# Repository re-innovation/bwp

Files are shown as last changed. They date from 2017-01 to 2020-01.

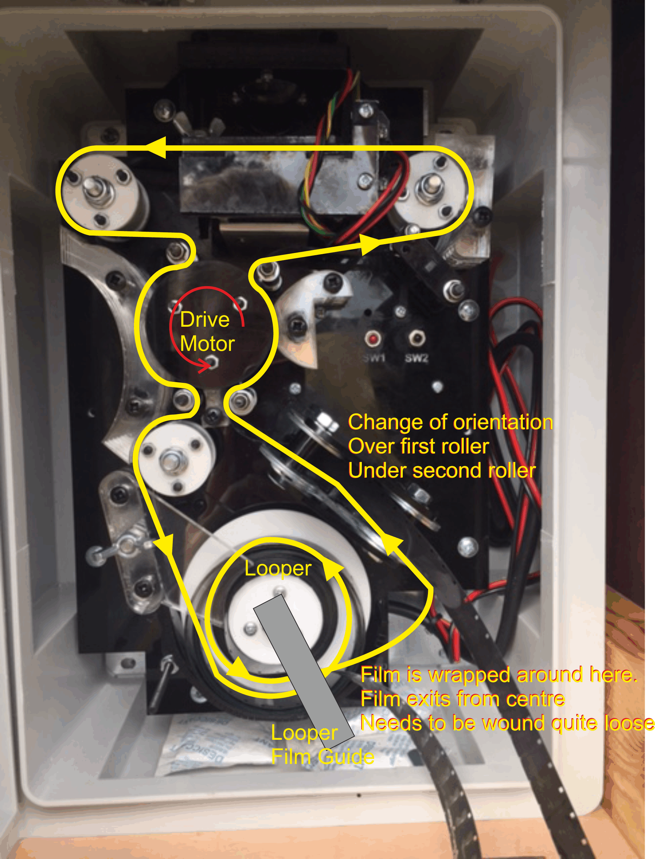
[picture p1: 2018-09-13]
Projection_Unit_Documentation/Kinetiscope Film Document.png

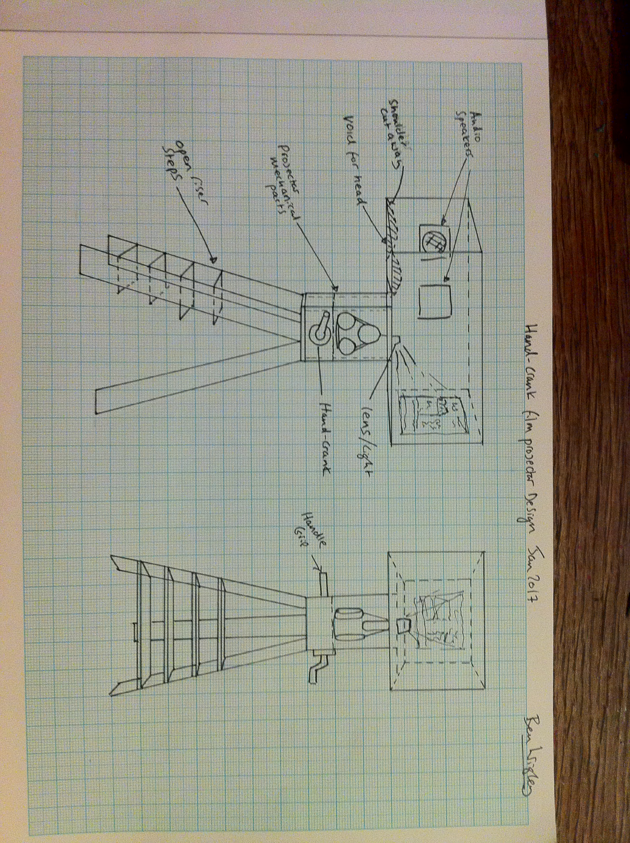
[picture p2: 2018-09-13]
Projection_Unit_Documentation/photo.JPG

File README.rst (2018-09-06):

===
BWP
===

This is the code and the design files for a low power LED projector unit which utilises real film.
It is quite complex and probably best explained via this link and video:

https://www.re-innovation.co.uk/portfolio/kinetiscopes-a-lost-paradise/

This repository has the full code (done by Matthew Mouse Gates) and the full design files (done by Matthew Little).

The desgin files have been produced using Corel Draw, but have been also saved as .dxf and .svg files. 

********
Controls
********

SW1 cycles through modes as follows:

- Setup: manual feed (SW2 feeds film)
- Setup: frame offset adjustment (SW2 adjusts the frame offset)
- Setup: volume adjustment (SW2 adjusts the volume)
- Setup: number of uses (readout)
- Setup: total runtime (readout)
- Setup: average runtime (readout)
- Normal Mode

****************
Heartbeat States
****************

The indicator LED is used to convey the state of the system by flashing one of the following sequences:

- Normal (50ms on, 500ms off) - the projector is running
- Slow (1000ms on, 150ms off) - the system has browned out, but still running
- Quick (25ms on, 25ms off) - the system is in configuration mode
- Slowest (1000ms on, 1000ms off) - the system has just powered up, but not exited brownout mode yet

**************
Pre-requisites
**************

* Install the Arduino IDE 1.6.6 or later:
    * Windows & Mac users may find a download link here: https://www.arduino.cc/en/Main/Software
    * Major Linux distros carry it in their software repositories, or the link above may be used
* Install *AccelStepper* library.
* Install *Mutila* library, link: https://github.com/matthewg42/Mutila 

******************************
Building Using the Arduino IDE
******************************

This method is preferred on Windows and for casual users who just want to build and use the project.

* Open Arduino IDE 
* Open firmware/firmware.ino
* Set the board to "Arduino Nano" (under the Tools -> Board menu)
* Connect Nano 
* Click the Upload button on the tool bar

*******************
Using make on Linux
*******************

This alternative build system may also be used. It is an alternative to using the Arduino IDE and may be preferred by some users. 

* Install the Arduino-Makefile system: https://github.com/sudar/Arduino-Makefile
* Edit the arduino.mk file and set the include line to point at where you installed Arduino-Makefile (or set the ARDUINO_MAKEFILE environment variable)
* In a shell, from the *firmware* directory, use the command "make upload" to build and install the code

****************
Uploading Sounds
****************

Sounds must be within a folder called "mp3" on the SD card.
Sounds are numbers 0001 to 9999.

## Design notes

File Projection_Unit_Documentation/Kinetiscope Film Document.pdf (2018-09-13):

To remove film - cut at break in film and re-fix.
This needs the film editing cutter.

To get film tension correct:
Ensure the film is wrapped around the looper and that the tension is OK (there needs to be enough space in the film to allow the centre film to exit the looper from the middle).
Use the drive motor to pull the film around. This can be rotated by hand when the unit is not powered.
The drive motor teeth must engage in the film holes.
Sometimes this slips, but should restore itself.

With lots of film then the film around the looper might pull tight and stick.
The film needs to be loosened by careful pulling and ‘shuffling’ of the film. Use the drive motor to pull the film around a few times. This will help loosen the film around the looper. This can be done by carefully turning the drive motor by hand (do not do this with power applied or crank turned).

The looper film guide stops all the film from springing off the looper.
The angle of the looper film guide can be altered to ensure the film is kept in place.
For the arch unit it was found to be best positioned at an angle of 5 c’clock. Ensure the film can feed through easily when the drive motor is turned.

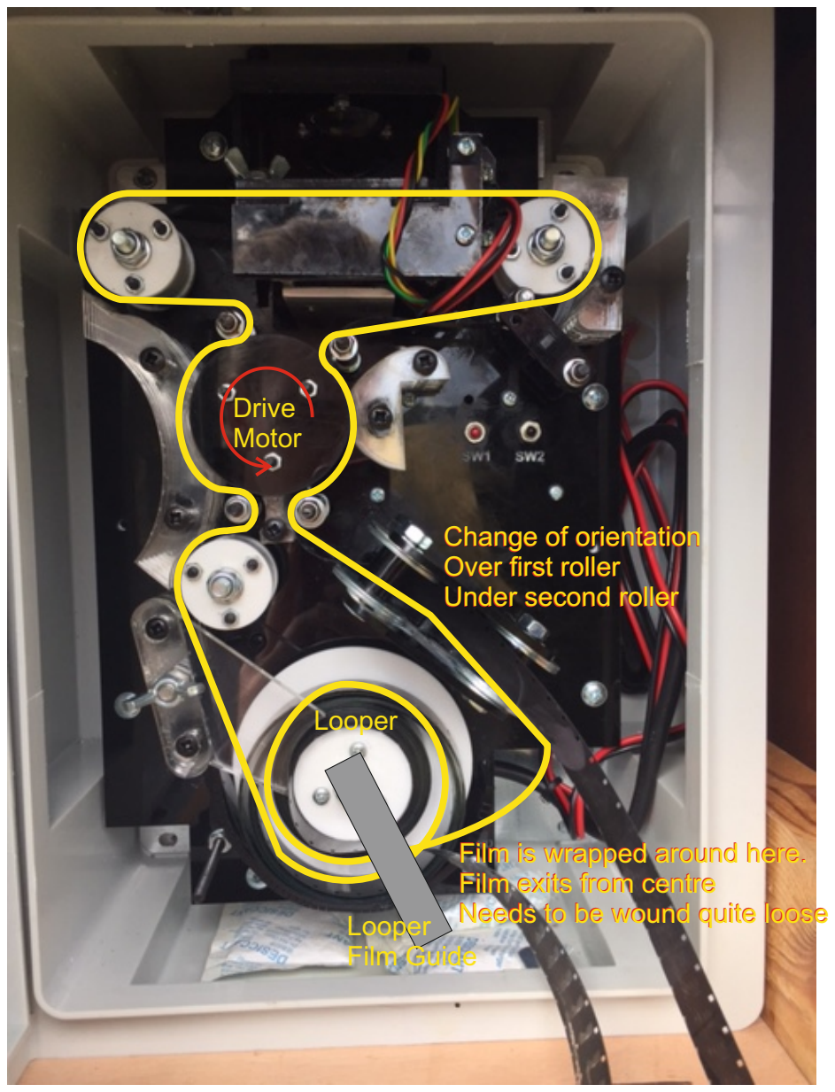
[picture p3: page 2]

Change of orientation
Over first roller
Under second roller

Film is wrapped around here. Film exits from centre
Needs to be wound quite loose

Change of orientation
Over first roller
Under second roller

Looper

Drive
Motor

Looper
Film Guide

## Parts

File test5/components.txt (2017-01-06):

Shutter
	open()
	close()

Mp3Player
	play(n)

Stepper
	advance()
	
FrameSync
	frameDetect
		Stepper.advance()
		Shutter.open()
		Shutter.close()

Mp3PlayerSyncSensor
	codeDetect
		Mp3Player.play(n)

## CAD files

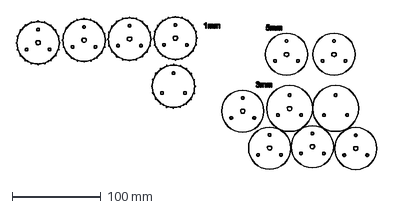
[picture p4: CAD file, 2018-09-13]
Projection_Unit_Hardware/Projection_Unit_Build/16mm_Film_Reel_Holder_7.dxf
407.2 x 173.0 mm

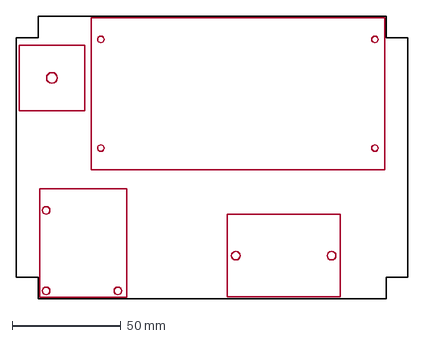
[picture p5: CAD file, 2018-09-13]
Solar Power Supply/Solar_Power_Supply_baseplate.dxf
180.0 x 130.0 mm

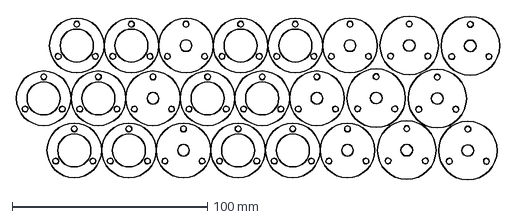
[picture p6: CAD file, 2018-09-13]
Projection_Unit_Hardware/Projection_Unit_Build/16mm_Film_Tension_roller_and_Feed_Rollers.dxf
247.6 x 83.9 mm

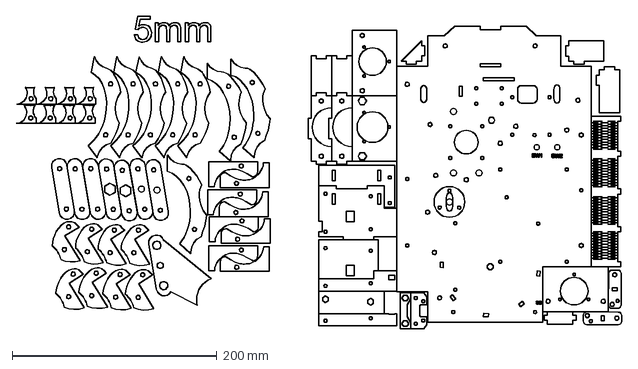
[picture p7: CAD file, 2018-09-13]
Projection_Unit_Hardware/Projection_Unit_Build/2017_5_3_Layout of components_v2_no_outline.dxf
591.4 x 305.5 mm

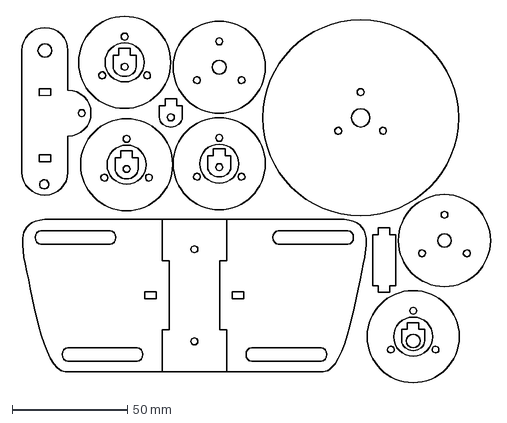
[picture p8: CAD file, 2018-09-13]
Projection_Unit_Hardware/Projection_Unit_Build/2017_4_6_Looper Design.dxf
205.8 x 159.1 mm

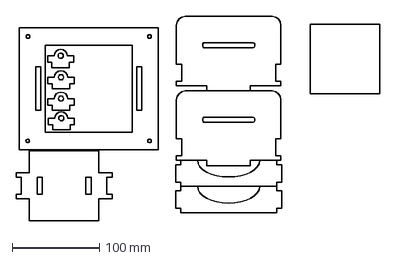
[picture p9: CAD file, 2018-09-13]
Projection_Unit_Hardware/Projection_Unit_Build/Mirror Holder.dxf
417.6 x 234.6 mm

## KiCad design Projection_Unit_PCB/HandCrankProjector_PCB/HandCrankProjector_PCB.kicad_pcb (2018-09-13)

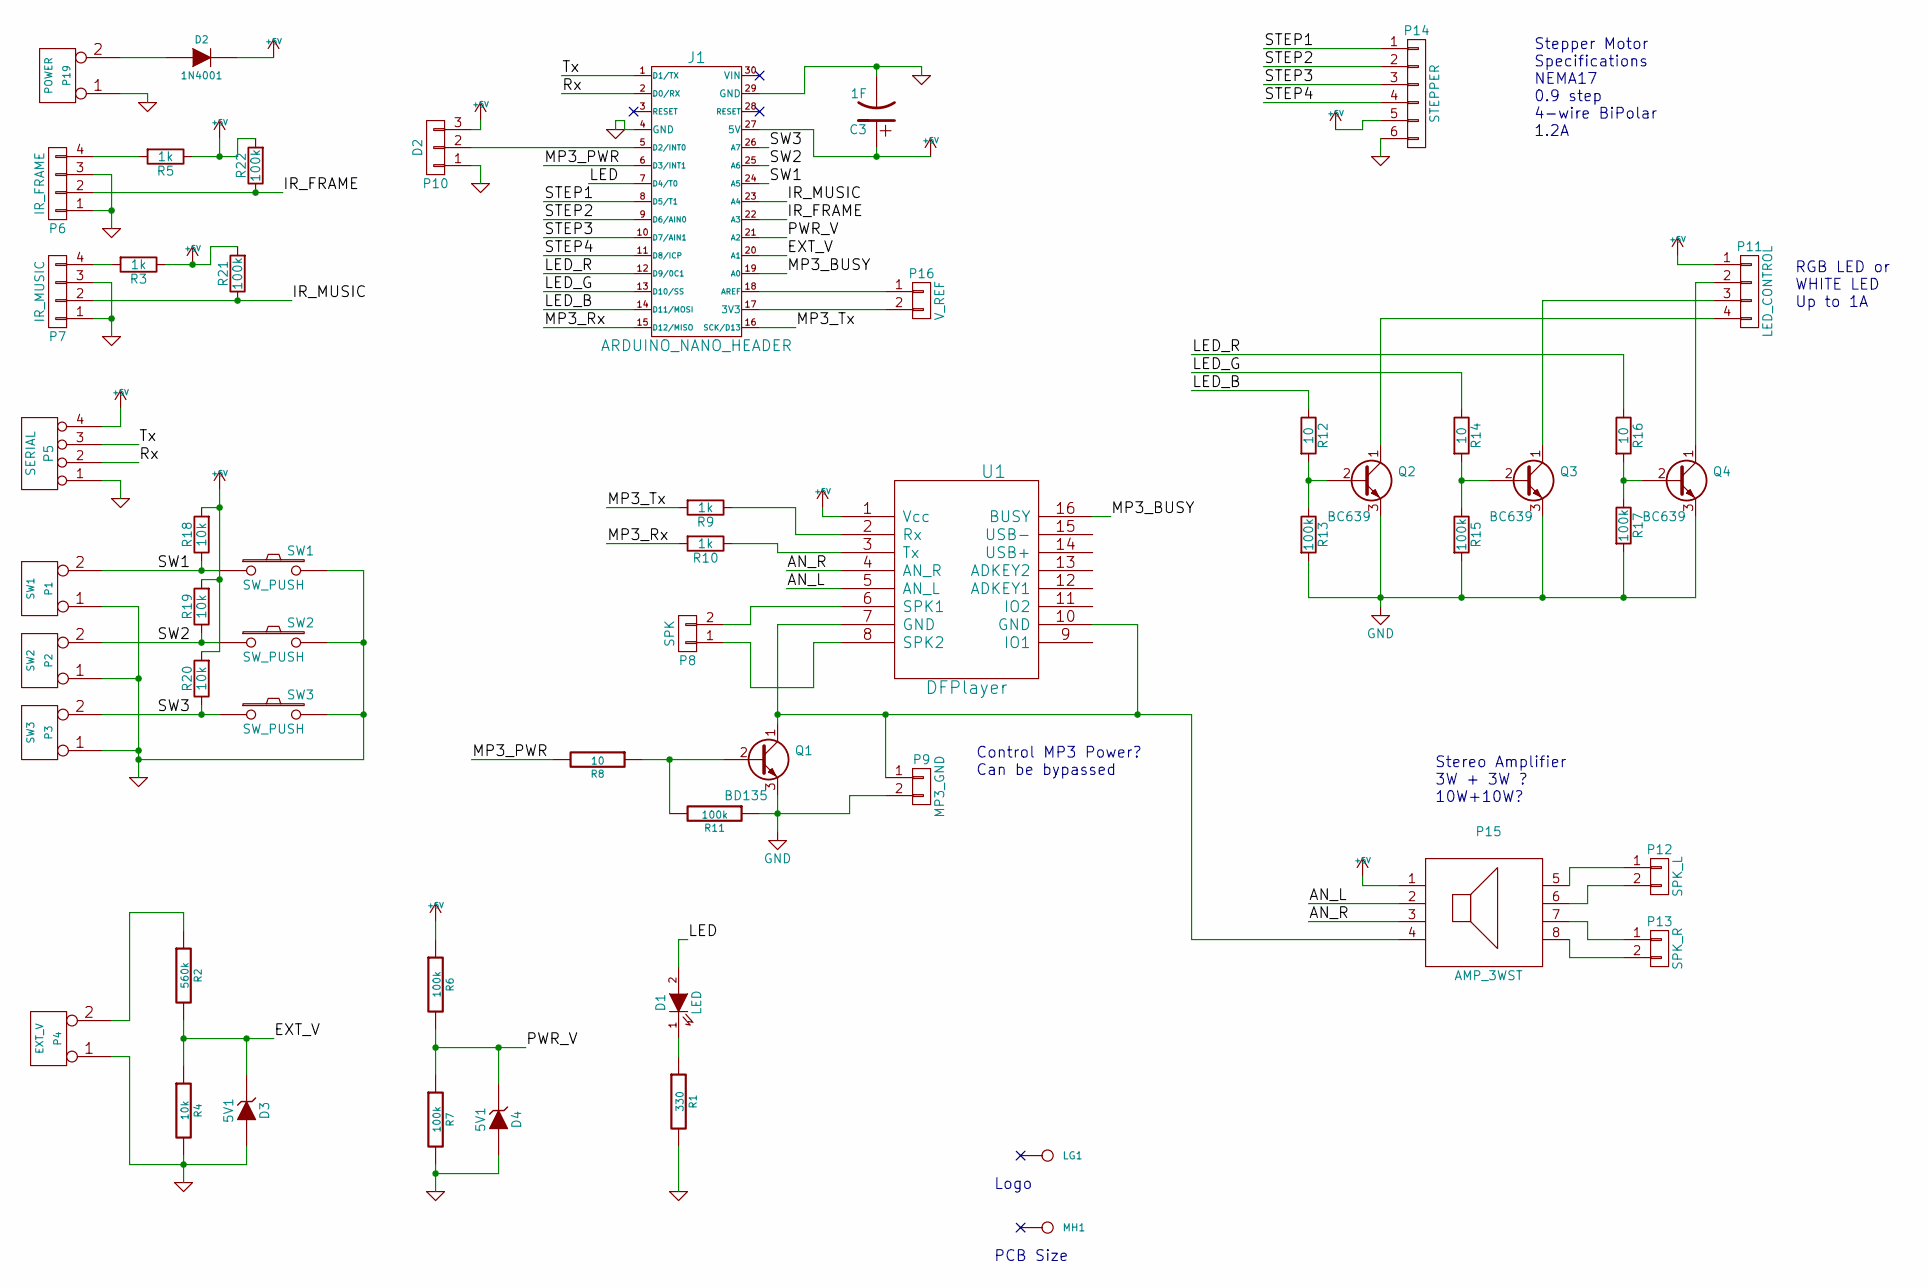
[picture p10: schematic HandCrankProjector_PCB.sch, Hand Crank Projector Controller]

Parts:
C3: 1F; C_1F_SuperCap; Manufacturer Part No Value
D1: LED; TH_LED-5MM_larg_pad
D2: 1N4001; TH_Diode_1
D3, D4: 5V1; TH_Diode_1
J1: ARDUINO_NANO_HEADER; NANO_DIP_30_600
LG1: CONN_1; reinnovation_logo_15mm
MH1: CONN_1; PCB_75x100mm
P1: SW1; SIL-2_large_hole
P2: SW2; SIL-2_large_hole
P3: SW3; SIL-2_large_hole
P4: EXT_V; SIL-2_screw_terminal
P5: SERIAL; SIL-4_Grove_SIL
P6: IR_FRAME; SIL-4_Grove_SIL
P7: IR_MUSIC; SIL-4_Grove_SIL
P8: SPK; SIL-2_screw_terminal
P9: MP3_GND; SM_2_SLDR_JMP
P10: D2; Pin_Header_Straight_1x03
P11: LED_CONTROL; SIL-4_Grove_SCREW
P12: SPK_L; SIL-2_screw_terminal
P13: SPK_R; SIL-2_screw_terminal
P14: STEPPER; TH_6W_SCREW_TERM
P15: AMP_3WST; TH_PAM8403_Amp
P16: V_REF; SM_2_SLDR_JMP
P19: POWER; SIL-2_screw_terminal; Manufacturer Part No Value
Q1: BD135; TO92-ECB_large_pad_BC639
Q2, Q3, Q4: BC639; TO92-ECB_large_pad_BC639
R1: 330; TH_Resistor_1; Manufacturer Part No Value
R2: 560k; TH_Resistor_1; Manufacturer Part No Value
R3, R5, R9, R10: 1k; TH_Resistor_1
R4: 10k; TH_Resistor_1; Manufacturer Part No Value
R6, R7, R11: 100k; TH_Resistor_1; Manufacturer Part No Value
R8: 10; TH_Resistor_1; Manufacturer Part No Value
R12, R14, R16: 10; TH_Resistor_1
R13, R15, R17, R21, R22: 100k; TH_Resistor_1
R18, R19, R20: 10k; TH_Resistor_1
SW1, SW2, SW3: SW_PUSH; SW_PUSH_single_pins
U1: DFPlayer; TH_DFPlayer_Mini

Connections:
+5V: C3.1, D2.2 (K), J1.27 (5V), P5.4, P10.3, P11.1, P14.5, P15.1, R3.1, R5.1, R6.1, R18.2, R19.2, R20.2, R21.2, R22.2, U1.1 (Vcc)
/AN_L: P15.2, U1.5 (AN_L)
/AN_R: P15.3, U1.4 (AN_R)
/EXT_V: D3.2 (K), J1.20 (A1), R2.2, R4.1
/IR_FRAME: J1.22 (A3), P6.2, R22.1
/IR_MUSIC: J1.23 (A4), P7.2, R21.1
/LED: D1.2 (A), J1.7 (D4/T0)
/LED_B: J1.14 (D11/MOSI), R12.1
/LED_G: J1.13 (D10/SS), R14.1
/LED_R: J1.12 (D9/0C1), R16.1
/MP3_BUSY: J1.19 (A0), U1.16 (BUSY)
/MP3_PWR: J1.6 (D3/INT1), R8.2
/MP3_Rx: J1.15 (D12/MISO), R10.2
/MP3_Tx: J1.16 (SCK/D13), R9.2
/PWR_V: D4.2 (K), J1.21 (A2), R6.2, R7.1
/Rx: J1.2 (D0/RX), P5.2
/STEP1: J1.8 (D5/T1), P14.1
/STEP2: J1.9 (D6/AIN0), P14.2
/STEP3: J1.10 (D7/AIN1), P14.3
/STEP4: J1.11 (D8/ICP), P14.4
/SW1: J1.24 (A5), P1.2 (PM), R18.1, SW1.1
/SW2: J1.25 (A6), P2.2 (PM), R19.1, SW2.1
/SW3: J1.26 (A7), P3.2 (PM), R20.1, SW3.1
/Tx: J1.1 (D1/TX), P5.3
GND: C3.2, D3.1 (A), D4.1 (A), J1.4 (GND), J1.29 (GND), P1.1, P2.1, P3.1, P4.1, P5.1, P6.1, P6.3, P7.1, P7.3, P9.2, P10.1, P14.6, P19.1, Q1.3 (E), Q2.3 (E), Q3.3 (E), Q4.3 (E), R1.2, R4.2, R7.2, R11.1, R13.2, R15.2, R17.2, SW1.2, SW2.2, SW3.2
unnamed: D1.1 (K), R1.1
unnamed: D2.1 (A), P19.2 (PM)
unnamed: J1.5 (D2/INT0), P10.2
unnamed: J1.17 (3V3), P16.2
unnamed: J1.18 (AREF), P16.1
unnamed: P4.2 (PM), R2.1
unnamed: P6.4, R5.2
unnamed: P7.4, R3.2
unnamed: P8.1, U1.8 (SPK2)
unnamed: P8.2, U1.6 (SPK1)
unnamed: P11.2, Q4.1 (C)
unnamed: P11.3, Q3.1 (C)
unnamed: P11.4, Q2.1 (C)
unnamed: P12.1, P15.5
unnamed: P12.2, P15.6
unnamed: P13.1, P15.7
unnamed: P13.2, P15.8
unnamed: P9.1, P15.4, Q1.1 (C), U1.7 (GND), U1.10 (GND)
unnamed: Q1.2 (B), R8.1, R11.2
unnamed: Q2.2 (B), R12.2, R13.1
unnamed: Q3.2 (B), R14.2, R15.1
unnamed: Q4.2 (B), R16.2, R17.1
unnamed: R9.1, U1.2 (Rx)
unnamed: R10.1, U1.3 (Tx)

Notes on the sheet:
PCB Size
Stepper Motor Specifications NEMA17 0.9 step 4-wire BiPolar 1.2A
Stereo Amplifier 3W + 3W ? 10W+10W?
Control MP3 Power? Can be bypassed
RGB LED or WHITE LED Up to 1A
Logo

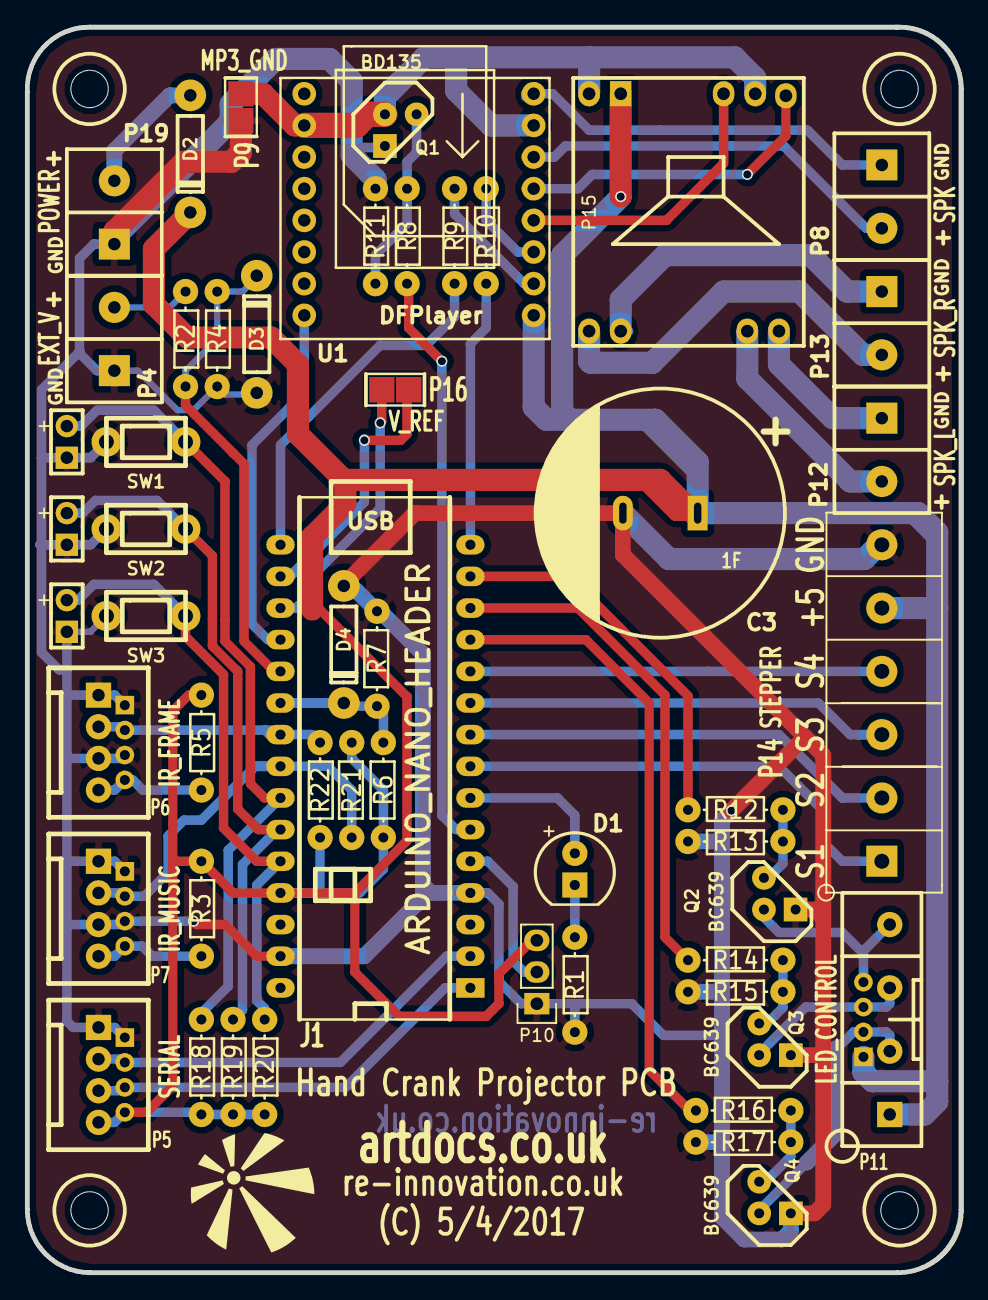
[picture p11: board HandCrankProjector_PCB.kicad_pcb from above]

Board: 2 copper layers, 74.9 x 99.9 mm, 55 parts (0 on the bottom side), 49 nets.

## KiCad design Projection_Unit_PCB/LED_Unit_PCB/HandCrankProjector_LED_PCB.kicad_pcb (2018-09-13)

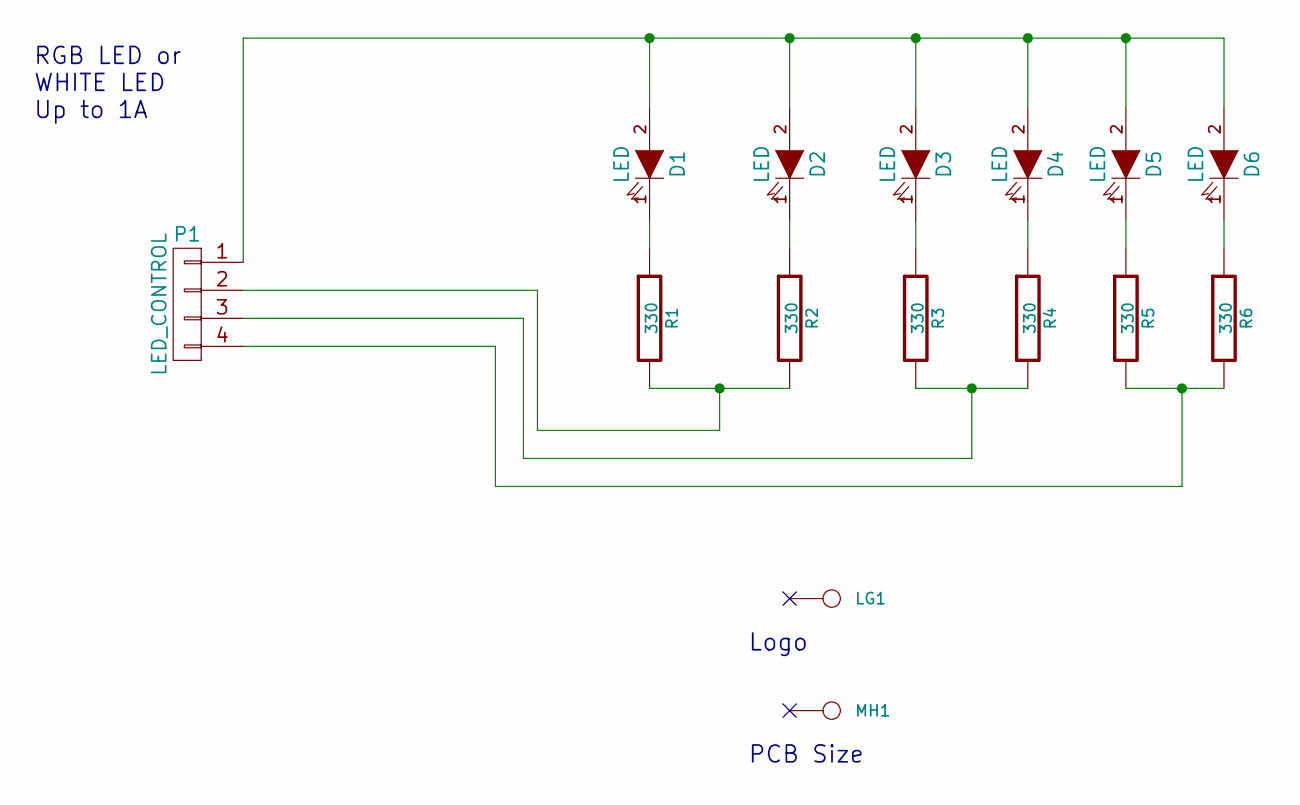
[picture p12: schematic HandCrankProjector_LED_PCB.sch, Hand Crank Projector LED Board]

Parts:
D1, D2, D3, D4, D5, D6: LED; TH_LED-5MM_larg_pad; Manufacturer Part No Value
LG1: CONN_1; reinnovation_logo_15mm
MH1: CONN_1; PCB_50x50mm
P1: LED_CONTROL; SIL-4_Grove_SCREW
R1, R2, R3, R4, R5, R6: 330; TH_Resistor_1; Manufacturer Part No Value

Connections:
unnamed: D1.1 (K), R1.1
unnamed: D1.2 (A), D2.2 (A), D3.2 (A), D4.2 (A), D5.2 (A), D6.2 (A), P1.1
unnamed: D2.1 (K), R2.1
unnamed: D3.1 (K), R3.1
unnamed: D4.1 (K), R4.1
unnamed: D5.1 (K), R5.1
unnamed: D6.1 (K), R6.1
unnamed: P1.2, R1.2, R2.2
unnamed: P1.3, R3.2, R4.2
unnamed: P1.4, R5.2, R6.2

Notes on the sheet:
PCB Size
RGB LED or WHITE LED Up to 1A
Logo

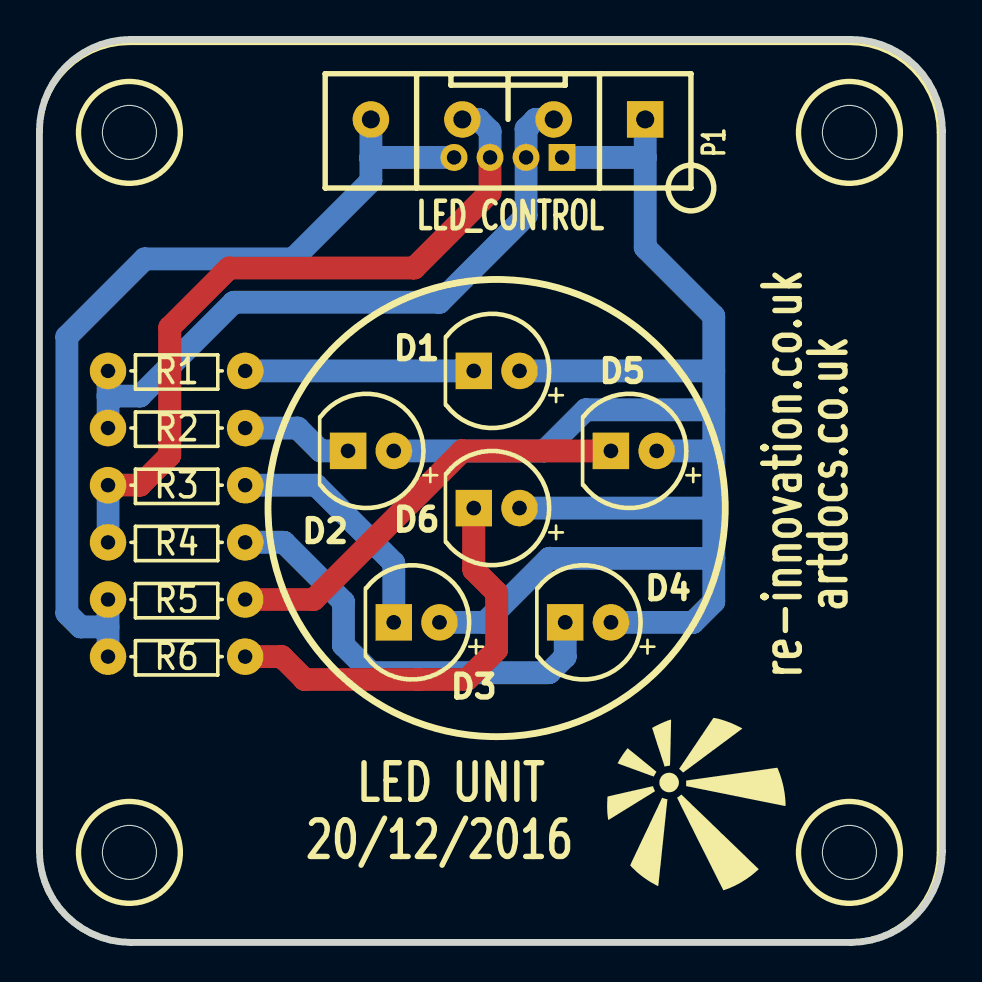
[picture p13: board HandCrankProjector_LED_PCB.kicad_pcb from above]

Board: 2 copper layers, 50.2 x 50.2 mm, 15 parts (0 on the bottom side), 10 nets.

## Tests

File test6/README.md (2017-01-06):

# Hamming code test (Linux)

Quick test of Hamming decoding functions in a stand-alone program which should build on any modern *nix system with gcc/C++ installed.

Goals:

1.  Decode sequences of 0's and 1's from a buffer
2.  Correct / error detect with Hamming code 8/12 method
3.  Endian-agnostic 

## Building

Running ''make test'' will build the program and run some tests (output should be manually reviewed).

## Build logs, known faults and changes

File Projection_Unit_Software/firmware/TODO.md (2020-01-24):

To Do
=====

New version of system will not be powered by hand crank. Instead will be powered 
by solar/battery power system. 

Changes to firmware:

* Should enter sleep mode when not active. This means
  - Arduno in power saving mode, use interrupts to wake up
  - DFPlayer Mini should be powered off while in sleep mode
  - Interrupts can come from either of the push buttons or a new crank sensor switch

* Crank sensor switch shows the crank is being turned (reed switch) on pin 2 (?)
  - If crank sensor triggers more than some threshold number of times per second, 
    system wakes into movie mode.

* MovieMode
  - Plays one [long] audio file.
  - Advances projector at constant rate.
  - Continues until cranking sensor stops getting regular pulses.

* Audio marks system will be removed from firmware.

* When the unit become inactive, Arduino should be put into sleep mode.
  - DFPlayer Mini should also be powered down when entering sleep mode

* Unit should also come out of sleep when buttons pressed to service
  diagnostic modes. Stats should also be printed to serial port.

* Require fix for integer overflow bug when reading out minutes of use 
  statistic.

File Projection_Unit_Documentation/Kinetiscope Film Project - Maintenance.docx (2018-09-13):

# Kinetiscope maintenance

Possible issues:

## No display from projector

Remove the grey plastic mechanical unit from the wooden projectors.

This is done with an M6 allen key to remove the bolts on the side of the unit.

There are 6 of these.

There is a piece of wood to hold the grey mechanical unit in place.

This is removed by loosening the two wood screws.

Open the grey mechanical unit using the handle.

When the film tension is not correct you can sometimes see that too much film has been pulled from the looper.

To get film tension correct:

Ensure the film is wrapped around the looper and that

the tension is OK (there needs to be enough space in the

film to allow the centre film to exit the looper from the

middle – this needs approximately a pencils width of space).

Carefully rotate the drive motor (shown on diagram) to pull the film around. This can be

rotated by hand when the unit is not powered.

The drive motor teeth must engage in the film holes.

Sometimes this slips, but should restore itself.

With lots of film then the film around the looper might pull tight and

stick.

The film needs to be loosened by careful pulling and ‘shuffling’ of the film.

Use the drive motor to pull the film around a few times. This will help

loosen the film around the looper. This can be done by carefully turning

the drive motor by hand (do not do this with power applied or crank turned).

The looper film guide stops all the film from springing off the looper.

The angle of the looper film guide can be altered to ensure the film is kept

in place.

For the arch unit it was found to be best positioned at an angle of 5 c’clock.

Ensure the film can feed through easily when the drive motor is turned.

## Hand crank not turning

Remove the handle and contact us.

If this has not improved the sitation then please contact us.

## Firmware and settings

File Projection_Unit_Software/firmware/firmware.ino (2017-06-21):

#include <Arduino.h>
#include <EEPROM.h>
#include <SoftwareSerial.h>
#include <AccelStepper.h>
#include <MutilaDebug.h>
#include <Mode.h>
#include <avr/wdt.h>

#include "SW1.h"
#include "SW2.h"
#include "SW3.h"
#include "ProjectorHeartbeat.h"
#include "Mp3Player.h"
#include "Projector.h"
#include "Settings.h"

#include "NormalMode.h"
#include "DiagnosticMode.h"



Mode* CurrentMode = &NormalMode;

void switchMode(Mode* newMode)
{
    CurrentMode->stop();
    CurrentMode = newMode;
    CurrentMode->start();
}

void setup()
{
    Serial.begin(115200);

    // We use an external reference for the VIN measurements
    analogReference(EXTERNAL);

    // Settings must be first because Mp3Player takes the volume from it.
    Settings.begin();

    Mp3Player.begin();
    if (!Mp3Player.check()) {
        Serial.println(F("WARNING: Mp3Player.check() failed"));
    }


    SW1.begin();
    SW2.begin();
    SW3.begin();
    ProjectorHeartbeat.begin();
    ProjectorHeartbeat.setMode(Heartbeat::Slower);
    Projector.begin();

    CurrentMode->start();

    // Enable watchdog timer
    wdt_enable(WDTO_500MS);

    DBLN(F("E:setup()"));
}

void loop()
{
    // Feed the watchdog
    wdt_reset();

    // Give timeslice to various components
    SW1.update();
    SW2.update();
    SW3.update();
    ProjectorHeartbeat.update();
    CurrentMode->update();
    Mp3Player.update();

    // Mode selection
    if (CurrentMode->isFinished()) {
        if (CurrentMode == &NormalMode) {
            switchMode(&DiagnosticMode);
        } else if (CurrentMode == &DiagnosticMode) {
            switchMode(&NormalMode);
        } else {
            DBLN(F("ERROR - we're in an unknown mode :s"));
        }
    }
}

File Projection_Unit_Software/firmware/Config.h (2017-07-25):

#pragma once

#include <Arduino.h>

// Stepper setup & constants
#define STEPPER_PIN_1               8
#define STEPPER_PIN_2               7
#define STEPPER_PIN_3               6
#define STEPPER_PIN_4               5
#define STEPPER_STEPS_PER_SEC       550
#define STEPPER_MAX_SPEED           1000

#define SHUTTER_OPEN_MS             125
#define SHUTTER_LED_R_PIN           9
#define SHUTTER_LED_G_PIN           10
#define SHUTTER_LED_B_PIN           11
#define SHUTTER_SYNC_PIN            A3
#define SHUTTER_SYNC_DIFF_THRESHOLD 250
#define SHUTTER_SYNC_MIN_STEPS      17
#define SHUTTER_SYNC_MAX_OFFSET     25
#define SHUTTER_SYNC_LOW_TRIGGER    50

#define MANUAL_FEED_STEPS_PER_SEC   200

#define AUDIO_SYNC_PIN              A4
#define AUDIO_SYNC_THRESH           200
#define AUDIO_SYNC_ALPHA            1.0
#define AUDIO_SYNC_MAX_LEN          35
#define AUDIO_SYNC_ZERO_MIN_LEN     2
#define AUDIO_SYNC_ONE_MIN_LEN      18
#define AUDIO_SYNC_ONE_MAX_LEN      100
#define AUDIO_SYNC_BITS             12
#define AUDIO_SYNC_INCOMPLETE       -1
#define AUDIO_SYNC_INVALID          -2

#define HEARTBEAT_LED_PIN           4

#define VIN_MONITOR_PIN             A1
#define VIN_R1                      10
#define VIN_R2                      680
#define VIN_REF                     3.3
#define VIN_PERIOD_MS               10
#define VIN_EMA_ALPHA               0.5
#define VIN_THRESH_LOW              8.0
#define VIN_THRESH_HIGH             10.0

#define VIN_INTERNAL_PIN            A2

#define MP3_TX_PIN                  12
#define MP3_RX_PIN                  13
#define MP3_BUSY_PIN                A0
#define MP3_POWER_PIN               3
#define MP3_VOLUME                  13
#define MP3_TRACK_NUMBER_OF_USES    190
#define MP3_TRACK_AVERAGE_RUNTIME   191
#define MP3_TRACK_TOTAL_RUNTIME     192
#define MP3_TRACK_MANUAL_FEED       193
#define MP3_TRACK_FRAME_OFFSET      194
#define MP3_TRACK_VOLUME_ADJUST     195
#define MP3_TRACK_AUDIO_MARK_COUNT  196
#define MP3_TRACK_VOLUME_TRACK      1
#define MP3_AUDIO_MARKS_MAX         10

#define SW1_PIN                     A5
#define SW2_PIN                     A6
#define SW3_PIN                     A7

#define EEPROM_ADDRESS_MAGIC        0
// If we don't see this in the magic address, zero the setting and set magic...
#define EEPROM_MAGIC                0x00000042
#define EEPROM_ADDRESS_USE_COUNT    (EEPROM_ADDRESS_MAGIC+sizeof(unsigned long))
#define EEPROM_ADDRESS_USE_SECONDS  (EEPROM_ADDRESS_USE_COUNT+sizeof(unsigned long))
#define EEPROM_ADDRESS_VOLUME       (EEPROM_ADDRESS_USE_SECONDS+sizeof(unsigned long))
#define EEPROM_ADDRESS_FRAME_OFFSET (EEPROM_ADDRESS_VOLUME+sizeof(uint16_t))
#define EEPROM_ADDRESS_AUDIO_COUNT  (EEPROM_ADDRESS_FRAME_OFFSET+sizeof(uint8_t))
#define EEPROM_ADDRESS_LAST_AUDIO   (EEPROM_ADDRESS_AUDIO_COUNT+sizeof(uint8_t))

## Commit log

2016-12-16 Initial commit
    Proof of concept test code for frame synchronisation.
2016-12-22 measure pulses with length from reflection sensor
2016-12-28 add class for stepper motor control
2017-01-02 audio mark reading raw bits
    Populates buffer ok (tested with TESTMODE and a pot, so
    would be good to test with actual device). Still need to
    implement hamming code de-coding routine.
2017-01-04 Implement new stripe format
    Thin white stripes mean zero, thicker ones mean one. The
    values AUDIO_SYNC_ZERO_MIN_LEN, AUDIO_SYNC_ONE_MIN_LEN,
    AUDIO_SYNC_ONE_MAX_LEN need to be set according to the size
    of the white stripes in stepper half-steps.
2017-01-05 don't forget to init Mp3 device
2017-01-05 tweaks/calibration for new code size
2017-01-05 test7 to figure wrong track playing
    Turns out should be usig the PlayTf command, not Play for the DFPlayer
    Mini device.
    [Config.h, Mp3Player.cpp, test7.ino]
2017-01-05 fixed frame sync done
    [Config.h, Mp3Player.cpp, Projector.cpp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]
2017-01-10 mode switching
2017-01-16 stop audio on brownout / mode change
    [NormalMode.cpp]
2017-01-16 diagnostic sub mode: frame sync adjust
2017-01-18 Rename buttons to match circuit board labels
2017-01-18 New pinout for prototype 2
2017-01-18 rename constants for button pins
2017-01-18 correct button config
2017-02-03 reset buttonstate / closeShutter
2017-02-03 debug frame sync
2017-02-06 tuning and testing sensors
2017-02-06 frame offset persistent
2017-02-06 fix arduino build / add dep docs
    [firmware.ino]
2017-05-11 Explicitly set stepper control LOW on brownout
    [NormalMode.cpp]
2017-05-12 fix volume after brownout
    [NormalMode.cpp]
2017-05-12 fix volume setting part 3
    [NormalMode.cpp]
2017-05-12 Watchdog; volume fix 3; heartbeat
    Watchdog timer added (500ms)
    Final (?!) fix for volume problem (explitit set before playing every
    sample). This is somewhat giving up, but it seems like the DFPlayer Mini
    is resetting at random times or something like that and there isn't time
    to full investigate, or the potential to fix the hardware, so explicity
    setting the volume every time seems like a reasonale compromise.
    Set the ProjectHeartbeat to show when in brownout mode.
    [NormalMode.cpp, Projector.cpp, firmware.ino]
2017-06-22 make a utility to help debug frame calc
2017-06-22 Minimum value detection
    We have noise on the film (numbers) which are adding noise to the frame
    detection. However, the noise is generally in the 300-800 range, so we
    will only trigger a frame if the low end of the leading edge is below
    some threshold (set with SHUTTER_SYNC_LOW_TRIGGER). It works well!
    [Config.h, Projector.cpp]
2017-07-11 Allow some slippage during long mark (1) read
    The film seems to slip sometimes, resulting in marks being seen as being
    too long. We can reduce the impact of this by allowing very long marks
    for the longer (1) values, si I increased the long mark max length to be
    very long. Won't catch slippage in shorter marks, but there's no easy
    fix for that in software.
    [Config.h]
2017-07-11 add audio mark failed read sequencing
    [Config.h, Projector.cpp]
2017-07-25 Don't enter diagnostic mode when browned out
    This fixes a subtle and occasional problem as the power in the storage
    cap dies... on occasion, as the last charge dissipates, the mode button
    input triggers (goes LOW), causing the unit to enter diagnostic mode...
    If the unit is re-powered between this time and the unit truly powering
    off, it will stay in diagnostic mode and appear not to work (as
    diagnostic mode starts with "manual feed", which does nothing until a
    button is pressed).
    [NormalMode.cpp]
2018-09-13 Adding all design files
    BIG update
    [16mm_Film_Reel_Holder_7.dxf, 16mm_Film_Tension_roller_and_Feed_Rollers.dxf, 2017_4_6_Looper Design.dxf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]
2019-12-07 cleanup obsolete files, fix bad location of files from master branch
    [Config.h, Mp3Player.cpp]
2019-12-07 update identifiers of standard track names for recent Mutila version
